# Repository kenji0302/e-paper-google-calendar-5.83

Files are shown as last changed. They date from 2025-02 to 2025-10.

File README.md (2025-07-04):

# Google Calendar を Raspberry Pi Pico W と e-paer で表示する

CleanShot 2025-05-28 at 22 43 03@2x

（左はサイズ比較用の Raspberry Pi Pico W）

## e-paper描画ライブラリについて

[Pico_ePaper_Code/python/Pico-ePaper-5.83-B.py at main · waveshareteam/Pico_ePaper_Code](https://github.com/waveshareteam/Pico_ePaper_Code/blob/main/python/Pico-ePaper-5.83-B.py) を元に一部修正したものをレポジトリに含めています。

## 準備

### 必要なもの

- [Raspberry Pi Pico WH — スイッチサイエンス](https://www.switch-science.com/products/8172?_pos=1&_sid=5aa1a1afe&_ss=r)
- [Raspberry Pi Pico用 5.83インチ e-Paper ディスプレイ（白黒赤）648×480 — スイッチサイエンス](https://www.switch-science.com/products/7319)

### なくても良いけどあると便利なもの

- [Amazon.co.jp: オーディオファン 電池ボックス USB出力対応 ON/OFF スイッチ付き USB-A メス 単3電池 4本 1.5V 6V (1.2V 4.8V) 単三電池 出力用 ケース : 産業・研究開発用品](https://www.amazon.co.jp/dp/B0B4W7Z1ML)
- [Amazon.co.jp: オーディオファン microUSB 短い ケーブル 両端子 L字 約12cm L字パターン2 ブラック AFSSLCBL : パソコン・周辺機器](https://www.amazon.co.jp/dp/B091GL481V?ref_=ppx_hzsearch_conn_dt_b_fed_asin_title_2&th=1)

## 追加するコード

日本語フォント（24pxのみ）。設置方法などは以下を参照。
[Raspberry Pi Pico W で e-paper に日本語を表示する その2（大きめのフォント表示） #micropython - Qiita](https://qiita.com/kenji0302/items/8da4c075dff974d1dc6f)

## 編集が必要なファイル

- secret.php
- secret.py

## Google の TOKEN 取得

```bash
mkdir data
php -S 0.0.0.0:8080
```

<http://localhost:8080> から Google 認証、REFRESH TOKENの取得 でテキストボックスに表示される。

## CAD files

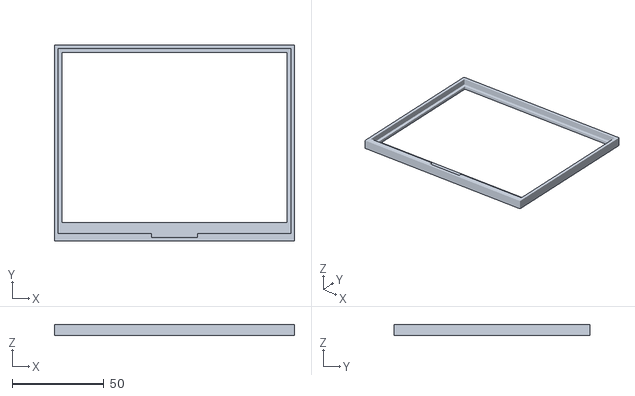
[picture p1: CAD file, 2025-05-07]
stl/lid.stl
131.0 x 107.0 x 6.00

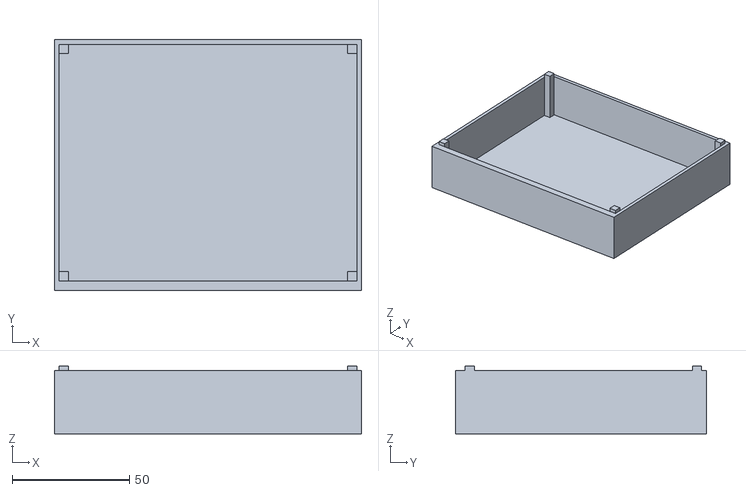
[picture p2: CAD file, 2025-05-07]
stl/body.stl
131.0 x 107.0 x 29.0

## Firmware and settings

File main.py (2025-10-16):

import urequests, ntptime, time, machine, sys
from cal import jst_ymd, wifi_connect, refresh_access_token, jpredtext, jpblacktext, jst_today_ymdhms_for_api, jst_ymdhms_str, jst_str_to_ymdw
from Pico_ePaper_5_83_B import EPD_5in83_B
from mfont import mfont
from secret import WIFI_SSID, WIFI_PASSWORD,GOOGLE_CLIENT_ID, GOOGLE_CLIENT_SECRET, GOOGLE_CALENDAR_ID, get_google_refresh_token
from machine import Pin

def main():

    # 処理が始まるとbusyになってしまうので、開発用のコンソール接続の余裕といて5秒待つ
    time.sleep(5)

    led = machine.Pin('LED', Pin.OUT)
    led.value(1)
    
    while True:

        machine.Pin(23, machine.Pin.OUT).high()

        # 画面表示

        mf = mfont()
        mf.setFontSize(24)

        led.value(0)
        time.sleep(0.2)
        led.value(1)

        error_count = 0
        while True:
            try:
                # Wifi接続
                wlan = wifi_connect(WIFI_SSID, WIFI_PASSWORD)
                # NTPで時間セット
                ntptime.settime()
                break
            except Exception as e:
                error_count += 1
                print("ネットワーク例外 : ", e)
                time.sleep(5)
                if error_count >= 3:
                    epd = epd_init()
                    jpredtext("ネットワークに問題が発生しました、リセットします。", 5, 10, mf, epd)
                    epd.display(epd.buffer_black, epd.buffer_red)
                    epd.delay_ms(2000)
                    machine.reset()

        led.value(0)
        time.sleep(0.2)
        led.value(1)
        time.sleep(0.2)
        led.value(0)
        time.sleep(0.2)
        led.value(1)

        # カレンダー取得
        access_token = refresh_access_token(GOOGLE_CLIENT_ID, GOOGLE_CLIENT_SECRET, get_google_refresh_token())

        led.value(0)
        time.sleep(0.2)
        led.value(1)
        time.sleep(0.2)
        led.value(0)
        time.sleep(0.2)
        led.value(1)
        time.sleep(0.2)
        led.value(0)
        time.sleep(0.2)
        led.value(1)

        # deepsleep1時間
        sleep_msec = 3600000
        if access_token is None:
            jpredtext("カレンダーにアクセス出来ません。", 30, 10, mf, epd)
            jpredtext("トークンを更新してください。", 30, 35, mf, epd)
        else:
            # ymd取得
            ymd = jst_ymd()

            # 画面初期化
            epd = epd_init()
            # データ更新日表示
            epd.imageblack.text("Updated at : " + jst_ymdhms_str(), 370, 473, 0x00)

            calendar_id = "primary"

            ymdhms = jst_today_ymdhms_for_api() 
            
            url = "https://www.googleapis.com/calendar/v3/calendars/" + GOOGLE_CALENDAR_ID + "/events?maxResults=13&timeMin=" + ymdhms + "&orderBy=startTime&singleEvents=True&timeZone=JST&fields=items(start,summary)"

            headers = {
                "Authorization": "Bearer " + access_token
            }

            response = urequests.get(url, headers=headers)

            if response.status_code == 200:

                events = response.json().get('items', [])            
                
                y = 10
                i = 0
                
                for event in events:
                    if 'date' in event['start']:
                        event_ymd = event['start']['date'][0:4] + event['start']['date'][5:7] + event['start']['date'][8:10]
                        event_str = jst_str_to_ymdw(event['start']['date']) + ' ' + event['summary']
                        print(event_str)
                    elif 'dateTime' in event['start']:
                        event_ymd = event['start']['dateTime'][0:4] + event['start']['dateTime'][5:7] + event['start']['dateTime'][8:10]
                        event_str = jst_str_to_ymdw(event['start']['dateTime'][0:10]) + event['start']['dateTime'][11:16] + ' ' + event['summary']
                        print(event_str)
                    
                    if event_ymd == ymd:
                        jpredtext(event_str, 30, y, mf, epd)
                    else:
                        jpblacktext(event_str, 30, y, mf, epd)
                    y = y + 37
            else:
                print("Failed to retrieve events:", response.status_code, response.text)

        epd.display(epd.buffer_black, epd.buffer_red)
        # sys.exit()
        print("deepsleep")
        
        # time.sleep_ms(sleep_msec)
        machine.Pin(23, machine.Pin.OUT).low()
        machine.deepsleep(sleep_msec)


def epd_init():
    """ePaperディスプレイを初期化して描画に備える。

    Returns:
        EPD_5in83_B: 全面を白/赤でクリアしたディスプレイインスタンス。
    """
    epd = EPD_5in83_B()
    epd.Clear(0xff, 0x00)
    epd.imageblack.fill(0xff)
    epd.imagered.fill(0x00)
    return epd


if __name__=='__main__':
    main()

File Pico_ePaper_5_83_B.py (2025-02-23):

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

from machine import Pin, SPI
import framebuf
import utime

# Display resolution
EPD_WIDTH       = 648
EPD_HEIGHT      = 480

RST_PIN         = 12
DC_PIN          = 8
CS_PIN          = 9
BUSY_PIN        = 13


class EPD_5in83_B():
    def __init__(self):
        self.reset_pin = Pin(RST_PIN, Pin.OUT)
        
        self.busy_pin = Pin(BUSY_PIN, Pin.IN, Pin.PULL_UP)
        self.cs_pin = Pin(CS_PIN, Pin.OUT)
        self.width = EPD_WIDTH
        self.height = EPD_HEIGHT
        
        self.spi = SPI(1)
        self.spi.init(baudrate=4000_000)
        self.dc_pin = Pin(DC_PIN, Pin.OUT)
        
        self.buffer_black = bytearray(self.height * self.width // 8)
        self.buffer_red = bytearray(self.height * self.width // 8)
        self.imageblack = framebuf.FrameBuffer(self.buffer_black, self.width, self.height, framebuf.MONO_HLSB)
        self.imagered = framebuf.FrameBuffer(self.buffer_red, self.width, self.height, framebuf.MONO_HLSB)
        self.init()

    def digital_write(self, pin, value):
        pin.value(value)

    def digital_read(self, pin):
        return pin.value()

    def delay_ms(self, delaytime):
        utime.sleep(delaytime / 1000.0)

    def spi_writebyte(self, data):
        # self.spi.write(bytearray(data))
        for i in range(0, len(data), 64):
            chunk = bytearray(data[i:i + 64])
            self.spi.write(chunk)

    def module_exit(self):
        self.digital_write(self.reset_pin, 0)

    # Hardware reset
    def reset(self):
        self.digital_write(self.reset_pin, 1)
        self.delay_ms(50) 
        self.digital_write(self.reset_pin, 0)
        self.delay_ms(2)
        self.digital_write(self.reset_pin, 1)
        self.delay_ms(50)   

    def send_command(self, command):
        self.digital_write(self.dc_pin, 0)
        self.digital_write(self.cs_pin, 0)
        self.spi_writebyte([command])
        self.digital_write(self.cs_pin, 1)

    def send_data(self, data):
        self.digital_write(self.dc_pin, 1)
        self.digital_write(self.cs_pin, 0)
        self.spi_writebyte([data])
        self.digital_write(self.cs_pin, 1)
        
    def send_data1(self, data):
        self.digital_write(self.dc_pin, 1)
        self.digital_write(self.cs_pin, 0)
        self.spi_writebyte(data)
        self.digital_write(self.cs_pin, 1)

    def ReadBusy(self):
        print("e-Paper busy")
        while(self.digital_read(self.busy_pin) == 0):      #  1: idle, 0: busy
            self.delay_ms(10)
        print("e-Paper busy release")  

    def TurnOnDisplay(self):
        self.send_command(0x12) 
        self.delay_ms(100)
        self.ReadBusy()
        
    def init(self):
        # EPD hardware init start     
        self.reset()
        
        self.send_command(0x01)     #POWER SETTING
        self.send_data (0x07)
        self.send_data (0x07)       #VGH=20V,VGL=-20V
        self.send_data (0x3f)       #VDH=15V
        self.send_data (0x3f)       #VDL=-15V

        self.send_command(0x04) #POWER ON
        self.delay_ms(100)  
        self.ReadBusy()   #waiting for the electronic paper IC to release the idle signal

        self.send_command(0X00)     #PANNEL SETTING
        self.send_data(0x0F)        #KW-3f   KWR-2F    BWROTP 0f   BWOTP 1f

        self.send_command(0x61)     #tres
        self.send_data (0x02)       #source 648
        self.send_data (0x88)
        self.send_data (0x01)       #gate 480
        self.send_data (0xe0)

        self.send_command(0X15)
        self.send_data(0x00)

        self.send_command(0X50)     #VCOM AND DATA INTERVAL SETTING
        self.send_data(0x11)
        self.send_data(0x07)

        self.send_command(0X60)     #TCON SETTING
        self.send_data(0x22)
        # EPD hardware init end
        return 0

    def display(self, imageBlack, imageRed):
        if (imageBlack == None or imageRed == None):
            return    
        self.send_command(0x10) # WRITE_RAM
        self.send_data1(imageBlack)
        self.send_command(0x13) # WRITE_RAM
        self.send_data1(imageRed)
        self.TurnOnDisplay()

    def Clear(self, colorBalck, colorRed):
        self.send_command(0x10) # WRITE_RAM
        for i in range(0, int(self.width / 8)):
            self.send_data1([colorBalck] * self.height)
            
        self.send_command(0x13) # WRITE_RAM
        for i in range(0, int(self.width / 8)):
            self.send_data1([colorRed] * self.height)
        self.TurnOnDisplay()

    def sleep(self):
        self.send_command(0x02) # DEEP_SLEEP_MODE
        self.ReadBusy()
        self.send_command(0x07)
        self.send_data(0xa5)
        
        self.delay_ms(2000)
        self.module_exit()

if __name__=='__main__':
    epd = EPD_5in83_B()
    epd.Clear(0xff, 0x00)
    
    epd.imageblack.fill(0xff)
    epd.imagered.fill(0x00)
    epd.imageblack.text("Waveshare", 0, 10, 0x00)
    epd.imagered.text("ePaper-5.83-B", 0, 25, 0xff)
    epd.imageblack.text("RPi Pico", 0, 40, 0x00)
    epd.imagered.text("Hello World", 0, 55, 0xff)
    epd.display(epd.buffer_black, epd.buffer_red)
    epd.delay_ms(2000)
    
    epd.imagered.vline(10, 90, 40, 0xff)
    epd.imagered.vline(90, 90, 40, 0xff)
    epd.imageblack.hline(10, 90, 80, 0x00)
    epd.imageblack.hline(10, 130, 80, 0x00)
    epd.imagered.line(10, 90, 90, 130, 0xff)
    epd.imageblack.line(90, 90, 10, 130, 0x00)
    epd.display(epd.buffer_black, epd.buffer_red)
    epd.delay_ms(2000)
    
    epd.imageblack.rect(10, 150, 40, 40, 0x00)
    epd.imagered.fill_rect(60, 150, 40, 40, 0xff)
    epd.display(epd.buffer_black, epd.buffer_red)
    epd.delay_ms(2000)

    for i in range(0, 5):
        epd.imageblack.fill_rect(200+100, i*20, 100, 10, 0x00)
    for i in range(0, 5):
        epd.imagered.fill_rect(200+0, i*20+100, 100, 10, 0xff)
    epd.display(epd.buffer_black, epd.buffer_red)
    epd.delay_ms(2000)

    epd.Clear(0xff, 0x00)
    epd.delay_ms(2000)
    print("sleep")
    epd.sleep()

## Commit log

2025-02-23 memory allocation failed に対処
    [Pico_ePaper_5_83_B.py]
2025-02-23 フォントサイズ記述変更
2025-02-24 fontサイズ修正
2025-03-02 更新処理中にLED点灯
2025-04-09 REFRESH TOKEN取得ツールを改善
2025-04-09 REFRESH TOKENをローカルのhttpサーバーから取得するよう変更
2025-05-07 ケースのモデルを追加
    [body.stl, lid.stl]
2025-05-07 電源、ケーブルを追記
2025-05-07 リフレッシュトークンをコードに埋め込む状態に変更
2025-05-13 sleepを6時間に変更
2025-05-16 deepsleepが長いとエラーになるため1時間に統一
2025-05-19 ntptimeのエラー時の処理追加、及びカレンダー更新日時表示の追加
2025-05-19 更新タイミング表示を日から日時に変更
2025-05-20 コメント修正
2025-05-20 エラーのカウント修正と動作確認用のLED点滅追加
2025-05-28 描画エリアの修正
2025-05-28 曜日の追加と日付の表示形式の調整
2025-07-04 スマホ対応
2025-10-06 画面初期化タイミングの変更
2025-10-16 説明に長文が入っていたときにメモリ不足でクラッシュする問題の修正
